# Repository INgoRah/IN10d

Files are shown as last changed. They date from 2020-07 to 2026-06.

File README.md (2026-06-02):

Arduino 1-Wire Homeautomation Base

# Changes
[x] timer based control (different switch table?). Use CLI sw t <bus> <adr> <latch> <bus> <adr> <pio>.
    Default 30 secs at the moment
[x] Host IF for switch table
[x] Host IF for control
[x] Host GPIO signal verified
[x] Switch with same dst does not clear timer if running.
[x] Log latch and switch

# Documentation

## Build
Create a post_extra_script.py to copy over to PI:
Import("env", "projenv")
env.AddPostAction(
    "$BUILD_DIR/${PROGNAME}.elf",
    env.VerboseAction(" ".join([
        "scp ",
        "$BUILD_DIR/${PROGNAME}.hex", "<user>@<ip>:<path>/${PROGNAME}.hex"
    ]), "Copying $BUILD_DIR/${PROGNAME}.hex")
)

Build using PlatformIO: %USERPROFILE%\.platformio\penv\Scripts\platformio.exe run --environment nanoatmega328-deploy

Debugging with "simulation" target

## Features Details

### Alarm handling

Each custom DS2408 generates an alarm signal of > 800 us on the OneWire line. No
other master supports detection of it. But this is a feature of the iButton.
Therefore I need a master to at least monitor the line and signal it to an
other master. The Arduino turned out to be fast and stable to handle basic
light switches in reasonable time compared to a Linux host (threads, updates,
script latency and overhead). So the Arduino controls the light switches.

### Address format and limitations

The adress scheme is aligned with the slave implementation to save space in
the Arduino Nano and speed up the lookup. Only bus and address needs to be known
(and detected in the alarm search).
The latch in the lookup table is only the latch number, no bitmap. Means pressing two
switches at the same time is ignored (first latch taken).

Slaves are based on the OneWireSlave Attiny code uses a format like this:
29 | id | bus | ~id | ~bus | 66 | 77 | CRC
with id: 0 .. F
PIO0/1 are output (usually, but can be configured)
Latch2..7 are input (usually)
A special destination type for other devices (like DS2413) is reserved.
The custom DS2408 implementation also serves a alarm signal of 900 us like
the iButtons do. This avoids frequent polling (would need to be around 200 ms)

### Switching examples ###

A button is pressed. The slave generates an alarm signal on the bus and the Arduino
detects the long signal (> 800 us). It starts polling using the alarm condition
for the (or all) slaves in alarm condition. Reads out the registers and
starts a lookup in the timer table and switch table for commands.

### Measures to overcome limitations

Still the lookup table could be too large and this needs to be mitigated.
- fixed or stable switches in program space: easy to access via different table
  or use custom bootloader for flash storing option
- lookup in EEPROM: cache EEPROM or create new look up table (bus|adr = 4 x 31 lines returns dst by latch index),  max 1 KB

## CLI examples

## I2C format
C3 - channel select like in DS2482
F0 - reset
69 - mode selection: [2] [4]
5A - search first device, wait for search cycle for reading, returns 0 if nothing found or | id | adr [8]
5B - search next device, returns 0 if nothing found or | id | adr [8]
01 - read one event from fifo, status: busy,ok,no_data
02 - add switch entry:  type, bus, adr1, latch, press [0..2], da.bus,da.adr,da.pio
03 - write PIO: type, bus, adr1, pio and release lock, check for an event acknowledging the change
E2 - lock i2c bus and get status, if no events in the queue the lock is released again
78 - Handle ack: pass the sequence number to be acked, this releases the lock

status: alarm bus 3 | alarm bus 2 | alarm bus 1 | alarm bus0
bus select
read out alarm : adr | latch
read out status : write adr | read PIO

### Host Communication

On GPIO low, read status register
Set read pointer:
    Write 0xE1 0xE1
Read one byte (status)
If event data (0x40)
    write 0x1
    status changes to BUSY, wait for OK or NO_DATA
    on ok send read data request
    write 0x96
    read data (on event 9 bytes): type, bus, adr, latch, press, 16 bit data, seq, 0xaa
    seq: 1..0x7f
    read status again and repeat if needed

### Handling events Implementation details:
- check alarm status which resets the gpio, ALARM_STATUS_REGISTER
   iic.i2cWriteSync(iicAdr, 2, Buffer.from([0xE1, 0xA8]));
- read one byte and check for 0x40 otherwise cancel
- request event data, selects status register
  The controller copies the data over from the fifo
  Send CMD_EVT_DATA (= 0x1)
    iic.i2cWriteSync(iicAdr, 1, Buffer.from([0x1]));
    release the bus iic.closeSync();
- read status in a loop till 0
    0 = ok, data is prepared
    1 = busy/waiting to read data
    0x80 no data: return
- select data register, status is READY = 0x4
    iic.i2cWriteSync(iicAdr, 1, Buffer.from([0x96]));
    delay...?
    iic.i2cReadSync(iicAdr, 9, rbuf);
    rbuf[7] contains the sequence number
- send ack
    This will clear the fifo entry and increases the sequence number.
    This also may release the I2C host bus
    iic.i2cWriteSync(iicAdr, 2, Buffer.from([0x78, rbuf[7]]));

### sending commands details
    set read ptr to DS2482_STATUS_REGISTER
    iic.i2cWriteSync(iicAdr, 2, Buffer.from([0xE1, 0xE1]));
    delay(1);
    // wait for ready
    do {
        iic.i2cReadSync(iicAdr, 1, rbuf);
        delay(1);
    } while (rbuf[0] != 0);

    iic.i2cWriteSync(iicAdr, 5, Buffer.from([0x3, bus, id, pio, <level>]));

## Switch configuration

sw : dumps the table
sw r : reads the table from eeprom again
sw s : saves the table into eeprom
sw c : clears the table
sw d <bus> <adr> <latch>: deletes a switch
sw s <bus> <adr> <latch> <dst bus> <dst adr> <dst pio> [type]
	add a switch
sw t <timer type> <bus> <adr> <latch> <dst bus> <dst adr> <dst pio> [type]
	Add a timed switch
    Timed table	timer type: 1 = 20 sec, 2: 30 sec, 3: 1 min, 4: 2 min, 5: 5 mins ...
    Timer on darkness: offset 10
	Timer on darkness with soft off per time if supported (dimmable), time 5 secs: offset 20

    latch 10 .. 17: long press
    latch 0 .. 7: normal press
    latch 20 .. 27: pressing

## EEPROM config space

3 6 0 1 0 0 3 0 80 1D 9 2
            vers=3 tbl@8 len=3
	                timed  @15 timed vers=2 len=0 / Max 40
			       16bit @ 17 vers=0 len=0 / Max 0

start:
pin 0 2 0 20 1 240
pin 2 7 0 60 1 250
pin 0 4 5 40 2 90
stop
pin 0 2 0 eb 0 0
pin 0 2 0 ee 0 0
on
pin 0 2 0 DD 0 254
pin 2 7 0 DD 0 254
off
pin 0 2 0 EB 0 0
pin 2 7 0 EB 0 0

brightness
pin 2 7 0 e3 250 0
pin 0 2 0 e3 250 250

threshold
pin 2 7 0 e5 236 0
pin 0 2 0 e5 228 0

cfg 7 w ff ff ff ff 20 ff ff ff ff ff ff 23 02 00 00 ff ff ff ff FC
             DD
          E4 20 0 A 6 4
cfg 7 w 1 e4 28 0 0 3 3 0 21 0 0 0 0 0 0
= level = 200
= time = 2 min
cfg 2 w 1 C0 30 0 A 3 3 0 21 0 0 0 0 0 0

        R |R |R |SW 1  2  3  4  5  6  7 |CFG 1 2  3  4  5  6  7 |FEA|OFF|MAJ|MIN|TYP
cfg 2 w F8 FF FF FF FF FF FF FF 20 FF FF 23 21 21 21 21 02 10 10
        T|TH|DD|DU|DF|T1|T2|SW 1  2  3  4  5  6  7
cfg 2 w 1 C0 20 00 0A 03 01 ff ff ff FF FF 21 FF FF FF FF FF FF
cfg 2 w 1
cfg 2

cfg 7 w 1
        T|TH|DD|DU|DF|T1|T2|SW 1  2  3  4  5  6  7
cfg 7 w 1 40 10 00 0A 01 01 FF 21 FF FF FF FF FF FF FF FF FF FF FF FF
p 2 7 0 30

cfg 7 w ff ff ff ff 20 ff ff ff ff ff ff 23 02 21 02 ff ff ff ff FC
cfg 1 w ff ff ff ff ff ff ff ff ff ff ff 02 02 02 02 ff ff ff ff FC

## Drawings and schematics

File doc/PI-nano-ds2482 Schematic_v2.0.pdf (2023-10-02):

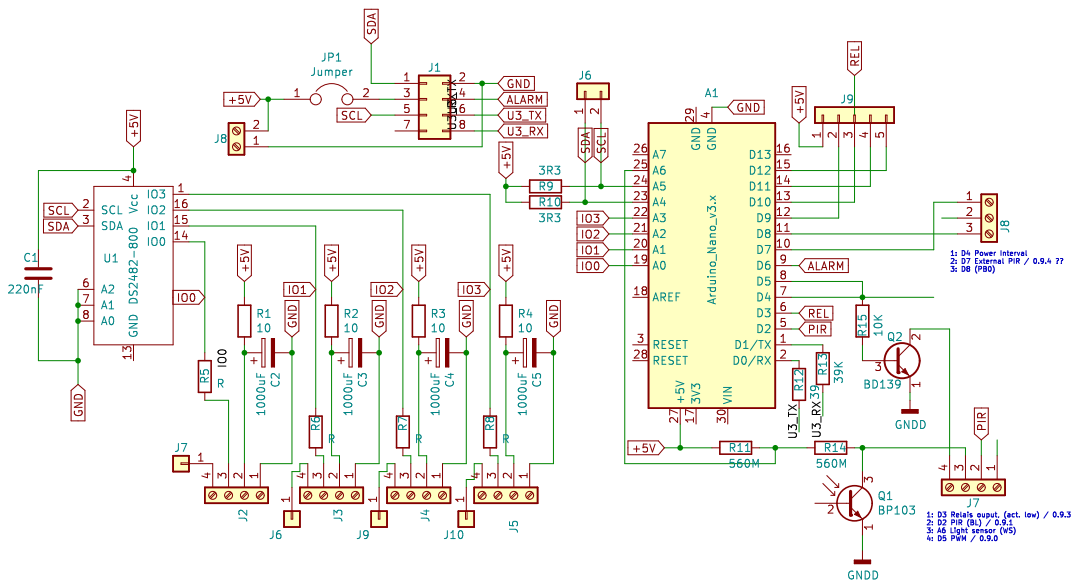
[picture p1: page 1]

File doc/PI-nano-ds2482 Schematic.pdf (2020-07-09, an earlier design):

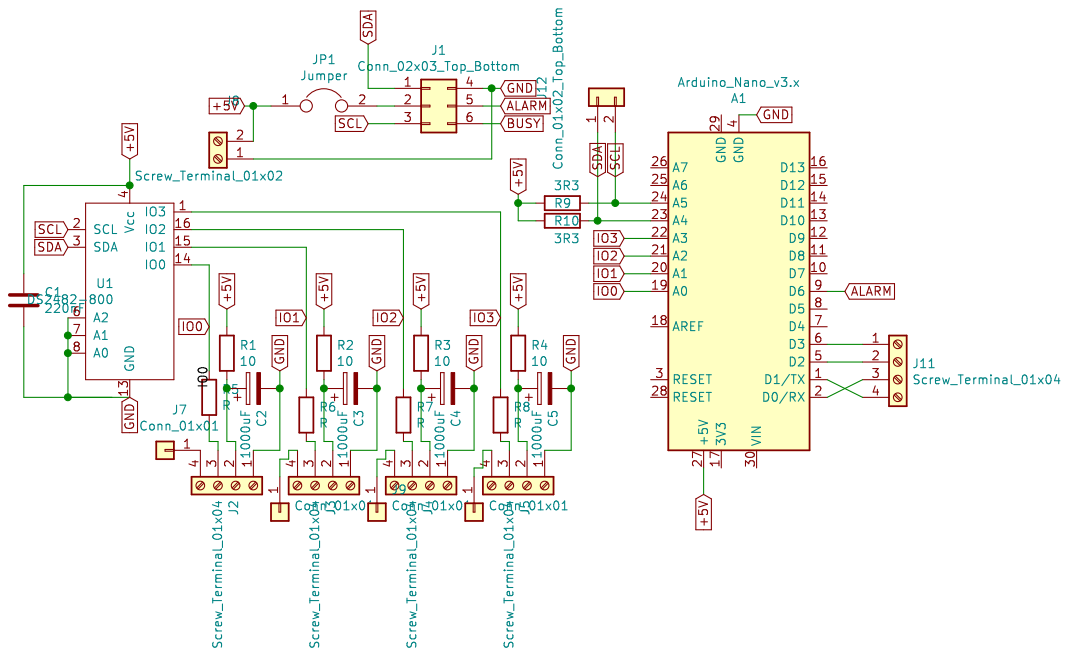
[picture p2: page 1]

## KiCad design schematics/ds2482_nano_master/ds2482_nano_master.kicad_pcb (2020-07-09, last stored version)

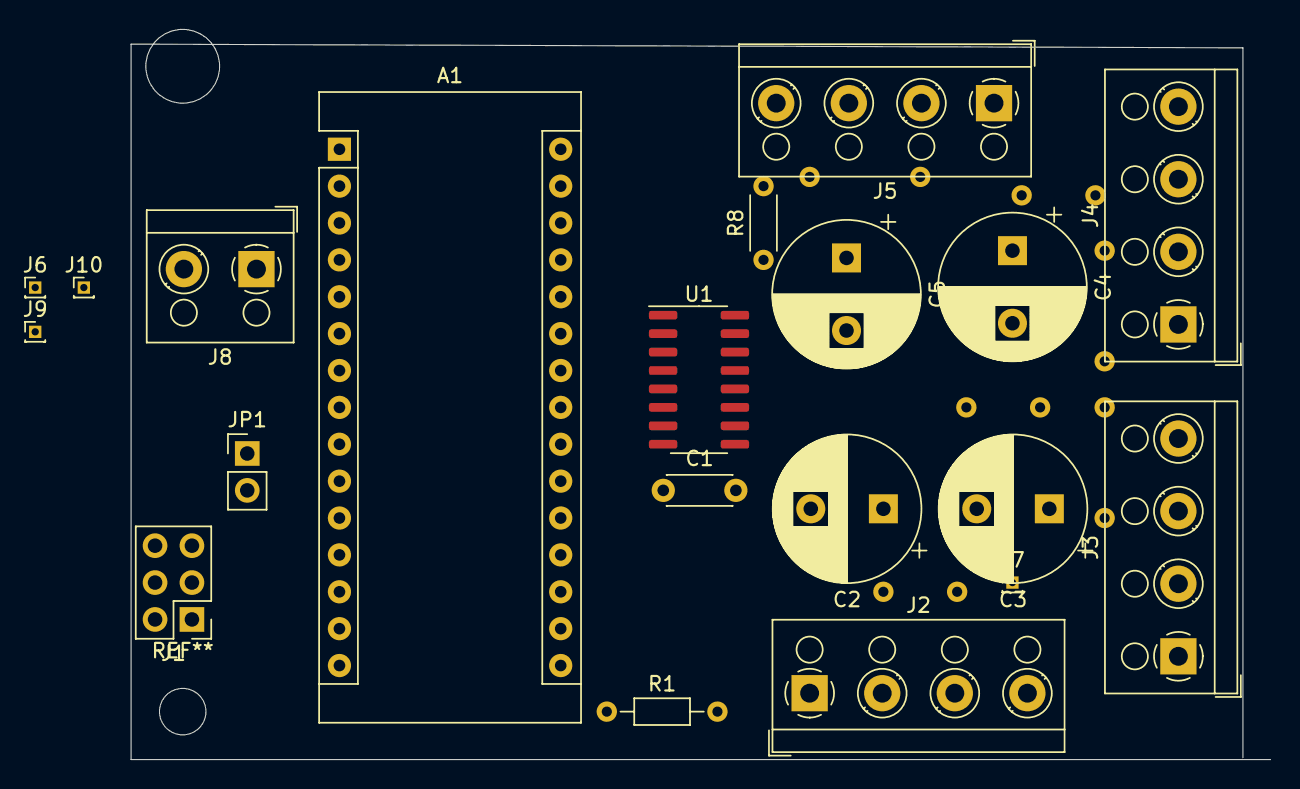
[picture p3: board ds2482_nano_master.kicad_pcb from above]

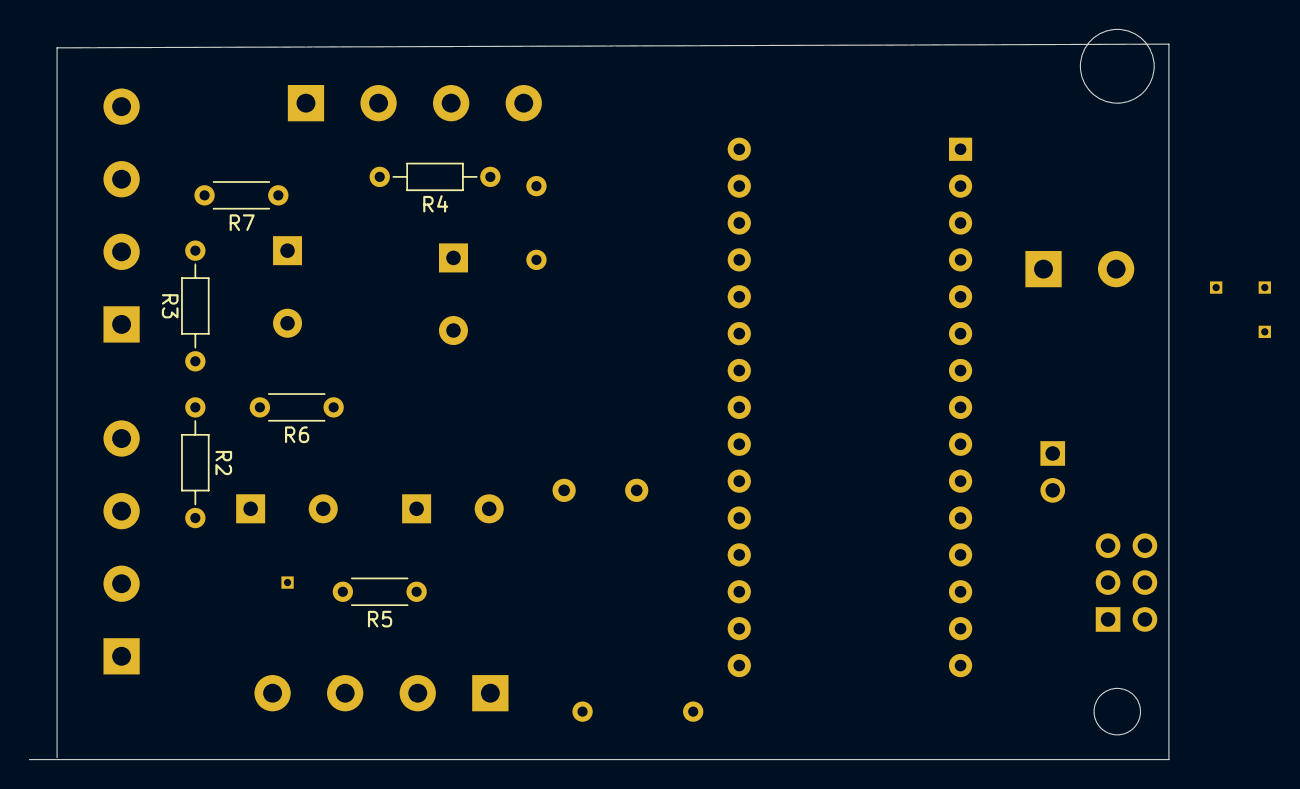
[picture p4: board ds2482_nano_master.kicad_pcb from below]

Board: 2 copper layers, 78.5 x 50.3 mm, 26 parts (6 on the bottom side), 22 nets, no tracks yet.

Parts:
A1: Arduino_Nano_v3.x; Arduino_Nano
C1: 220nF; C_Disc_D4.3mm_W1.9mm_P5.00mm
C2, C3, C4, C5: 1000uF; CP_Radial_D10.0mm_P5.00mm
J1: Conn_02x03_Top_Bottom; PinHeader_2x03_P2.54mm_Vertical
J2, J3, J4, J5: Screw_Terminal_01x04; TerminalBlock_RND_205-00003_1x04_P5.00mm_Horizontal
J6, J7, J9, J10: Conn_01x01; PinHeader_1x01_P1.00mm_Vertical
J8: Screw_Terminal_01x02; TerminalBlock_RND_205-00001_1x02_P5.00mm_Horizontal
JP1: Jumper; PinHeader_1x02_P2.54mm_Vertical
R1, R2, R3, R4: 10; R_Axial_DIN0204_L3.6mm_D1.6mm_P7.62mm_Horizontal
R5, R6, R7, R8: R; R_Axial_DIN0204_L3.6mm_D1.6mm_P5.08mm_Horizontal
U1: DS2482-800; SOIC-16_3.9x9.9mm_P1.27mm

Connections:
+5V: A1.27, C1.1, J8.2, R1.1, R2.1, R3.1, R4.1, U1.4
ALARM: A1.9, J1.5
GND: A1.4, C1.2, C2.2, C3.2, C4.2, C5.2, J1.4, J2.1, J3.1, J4.1, J5.1, J8.1, U1.6, U1.7, U1.8, U1.13
IO0: A1.19, R5.1, U1.14
IO1: A1.20, R6.1, U1.15
IO2: A1.21, R7.1, U1.16
IO3: A1.22, R8.1, U1.1
unnamed: C2.1, J2.2, R1.2
unnamed: C3.1, J3.2, R2.2
unnamed: C4.1, J4.2, R3.2
unnamed: C5.1, J5.2, R4.2
unnamed: J1.2, JP1.2
unnamed: J2.3, R5.2
unnamed: J2.4, J7.1
unnamed: J3.3, R6.2
unnamed: J3.4, J6.1
unnamed: J4.3, R7.2
unnamed: J4.4, J9.1
unnamed: J5.3, R8.2
unnamed: J5.4, J10.1
SCL: A1.24, J1.3, U1.2
SDA: A1.23, J1.1, U1.3

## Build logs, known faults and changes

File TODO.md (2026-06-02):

# Bugs
Pressing a button to permanently switch on light is not working setting level = 100 turns light off

# Improvements

[ ] Separate latch (input) and switch (output) to send two message in case
of auto, switch table or host controlled switch  
[ ] (ongoing) Timer based on light with configurable threshold
    - update brightness on change to slaves 2.7 and 0.2
[ ] Custom timer time per switch  
[ ] (ongoing) Host IF for status read  
[ ] Light independed timed switch. Currently timed switches only if dark  
[ ] Support 16 bit destination address for all PIOs
[ ] Support timed switch from host
[ ] Timed switches retrigger/switch. Now every latch retriggers timer, but it could
    instead switch off again. This needs to be configurable per switch
[ ] Slave based timer time configurable (needs change in owslave)

# PICO Support

## Adaptations

- OneWire Montor (Pull-Up)
- Ports (Analog, digital, PWM)
- IO changes

## Features

### MQTT Receiver (Port switcher)

### MQTT Sender (Temperature, status)

### Change switch table data struct

- address up to 8 PIOs (3 bits)
- optional address up to 8 busses (3 bits)

### Support non custom Addresses

- DS1820 based sensors (requires polling)
- full 1-wire address (except CRC)

# Switch Table
= Switches =
1.11.5 -> 2.3.0 (2D42 | 86)
2.3.4 -> 1.B.1 (D04 | 57)
1.1.7 -> 1.C.1 (5C2 | 59)
2.1.6 -> 2.3.0 (584 | 86)
2.2.3 -> 2.3.0 (8C4 | 86)
1.11.7 -> 1.1.1 (2DC2 | 43)
1.11.27 -> 1.5.0 (2DE2 | 4A)
1.11.25 -> 1.5.1 (2D62 | 4B)
0.6.7 -> 0.5.0 (19C0 | A)
0.6.4 -> 0.8.0 (1900 | 10)
0.5.5 -> 0.8.0 (1540 | 10)
0.5.7 -> 0.6.0 (15C0 | C)
0.5.3 -> 0.1.0 (14C0 | 2)
1.12.7 -> 1.5.1 (31C2 | 4B)
1.12.5 -> 1.1.1 (3142 | 43)
1.12.15 -> 2.7.0 (33C2 | 8E)
1.12.25 -> 0.9.0 (3162 | 12)
1.12.26 -> 2.7.0 (31A2 | 8E)
1.1.6 -> 1.C.1 (582 | 59)
1.7.2 -> 0.9.0 (1C82 | 12)
0.8.5 -> 0.6.0 (2140 | C)
0.8.7 -> 0.8.0 (21C0 | 10)
1.4.6 -> 1.1.1 (1182 | 43)
1.4.4 -> 1.C.1 (1102 | 59)
1.7.6 -> 1.5.0 (1D82 | 4A)
1.7.4 -> 1.5.1 (1D02 | 4B)
1.1.18 -> 1.1.0 (612 | 42)
1.7.2 -> 2.7.0 (1C82 | 8E)
1.1.16 -> 1.5.1 (592 | 4B)
0.6.5 -> 0.1.0 (1940 | 2)
2.2.23 -> 2.7.0 (8E4 | 8E)
1.7.5 -> 1.1.1 (1D42 | 43)
1.4.14 -> 1.5.1 (1112 | 4B)
1.12.8 -> 1.B.1 (3202 | 57)
1.12.17 -> 1.5.0 (31D2 | 4A)
1.7.3 -> 1.B.1 (1CC2 | 57)
1.7.7 -> 0.1.0 (1DC2 | 2)
1.4.16 -> 1.3.0 (1192 | 46)
Size=114/540
= Timed =
Type 21 0.9.1 -> 0.9.0
Type 21 2.7.2 -> 2.7.0
Type 22 1.11.23 -> 0.9.1
Size=9/40

  0: 2 FF 72 0 42 2D 86 4 D 57 C2 5 59 84 5 86 
 16: C4 8 86 C2 2D 43 E2 2D 4A 62 2D 4B C0 19 A 0 
 32: 19 10 40 15 10 C0 15 C C0 14 2 C2 31 4B 42 31 
 48: C2 33 8E 62 31 12 A2 31 8E 82 5 59 82 1C 12 
 64: 21 C C0 21 10 82 11 43 2 11 59 82 1D 4A 2 
 80: 4B 12 6 42 82 1C 8E 92 5 4B 40 19 2 E4 8 
 96: 42 1D 43 12 11 4B 2 32 57 D2 31 4A C2 1C 57 
112: 1D 2 92 11 46 2 15 8 0 15 40 24 12 15 84 
128: 1C 8E 24 12 15 84 1C 8E 8 D2 2C C2
142:

  0: 3 6 E 2 1 FF 72 0 42 2D 86 4 D 57 C2 5 
 16: 59 84 5 86 C4 8 86 C2 2D 43 E2 2D 4A 62 2D 4B 
C0 19 A 0 19 10 40 15 10 C0 15 C C0 14 2 C2 
31 4B 42 31 43 C2 33 8E 62 31 12 A2 31 8E 82 5 
59 82 1C 12 40 21 C C0 21 10 82 11 43 2 11 59 
82 1D 4A 2 1D 4B 12 6 42 82 1C 8E 92 5 4B 40 
19 2 E4 8 8E 42 1D 43 12 11 4B 2 32 57 D2 31 
4A C2 1C 57 C2 1D 2 92 11 46 2 40 8 0 15 40 
24 12 15 84 1C 8E 1 8E 3 0 15 40

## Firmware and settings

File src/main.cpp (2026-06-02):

/* LICENSE
 *
 */
/*
 * Includes
 */
#include <avr/sleep.h>
#include <avr/pgmspace.h>
#include <avr/wdt.h>

#include "main.h"

#define wdr wdt_reset

/*
 * Library classs includes
 */
#include <Wire.h>
#include <OneWireBase.h>
#include <DS2482.h>
#include "WireWatchdog.h"
#include "TwiHost.h"
#ifdef CLI_SUPPORT
#include "CmdCli.h"
#endif
#include "OwDevices.h"
#include "SwitchHandler.h"

/*
Used pins
(D0 .. D7 = PD0 .. PD7,
 D8 .. D13 = PB0 .. PB5,
 A0 .. A5 = PC0 .. PC5):
D2 - Internal PIR, maps to 0.9.1
D3 -
D4 - Misc Alarm PIN, maps to 0.9.2
D5 - PWM output (dimed LED) via open coollector transistor, maps to 0.9.0
D6 - used for alarm signal to host (class TwiHost)
D7 - Power Interval
D8 (PB0) - External PIR, maps to 0.9.4
D9 -
D10 - Relais ouput, negative polarity - active switching GND, maps to 0.9.3
D11 -
D12 -
D13 - built in LED
A0..A4 - 1-wire monitor
A6 (ADC6) - Light sensor (analog)
*/
/*
Virtual adress mapping
0.9.0 - output PWM on D5
0.9.1 - output D9
0.9.2 - input Misc Alarm PIN / D12
0.9.3 - output D10
0.9.4 - D11
0.9.5 - ignored
0.9.7 - ignored
x - input D3
*/

/*
 * Local constants
 */
#define LED_ON() digitalWrite(13, 1); \
					ledOn = 1;
#define LED_OFF() digitalWrite(13, 0); \
					ledOn = 0;
#define HOST_SLAVE_ADR 0x2f
#define ALARM_SRCH_RETRY 15

byte debug;
byte pins;

/*
 * Objects
 */
TwiHost host;
DS2482 ds1(0);
OwDevices ow;
SwitchHandler swHdl (&ow);
OneWireBase *ds = &ds1;

uint8_t sec;
uint8_t min;
uint8_t hour;
uint8_t light;
byte light_sensor = 1;
uint16_t pow_imp;

#if !defined(AVRSIM)

WireWatchdog wdt0(A0);
WireWatchdog wdt1(A1);
WireWatchdog wdt2(A2);
WireWatchdog wdt3(A3);
#if MAX_BUS > 3
WireWatchdog* wdt[MAX_BUS] = { &wdt0, &wdt1, &wdt2, &wdt3 };
#else
WireWatchdog* wdt[MAX_BUS] = { &wdt0, &wdt1, &wdt2 };
#endif

#ifdef CLI_SUPPORT
CmdCli cli;
#endif
/*
 * Local variables
 */
byte alarmSignal, pinSignal, ledOn = 0;
#ifdef EXT_DEBUG
byte wdFired;
#endif
#if 0
unsigned long wdTime = 0;
#endif
static unsigned long alarmPolling = 0;
uint8_t *hostBuf = NULL;

/*
* Function declarations
*/
#ifdef EXT_DEBUG
static void ledBlink();
unsigned long ledOnTime = 0;
#endif
static void check_light(byte mode);
void light_loop();
void pin_loop();
void alarm_loop();

/*
* Function definitions
*/
void setup() {
	int i;
	/* the watchdog timer remains active even after a system reset (except a
	 * power-on condition), using the fastest prescaler value.
	 * It is therefore required to turn off the watchdog early
	 * during program startup */
	MCUSR = 0;
	wdt_disable();
	Serial.begin(115200);

	debug = 3;
	pins = 0xff;
	Serial.print(F("IN10D "));
	Serial.println(F(VERS_TAG));
	//digitalWrite(3, 1);
	//pinMode(3, OUTPUT);
	delay (10);
	// host.onCommand(hostCommand);
	host.begin (HOST_SLAVE_ADR);
#ifdef EXT_DEBUG
	wdFired = 0;
#endif
	ow.begin(ds);
	// reads also mode and debug
	swHdl.begin(ds);
	if (pins & 0x1)
		pinMode(4, INPUT_PULLUP);
	if (pins & 0x2)
		pinMode(3, INPUT);
	byte mask = 0x10;
	for (i = 9; i < 13; i++) {
		if (pins & mask) {
			digitalWrite(i, HIGH);
			pinMode(i, OUTPUT);
		}
		mask = mask << 1;
	}
	/* enable interupts on PB0 (= D8), Power impulse */
	PCMSK0 |= (_BV(PCINT0));
	/* enable interrupts for the 1-wire monitor */
	PCMSK1 |= (_BV(PCINT8) | _BV(PCINT9) | _BV(PCINT10) | _BV(PCINT11));
	if (pins != 0) {
		/* enable interupts on PD2, PD3, PD7 (4, 7) (= D2, D3, D4, D7) */
		PCMSK2 |= (_BV(PCINT18) | _BV(PCINT19) | _BV(PCINT23) /*| _BV(PCINT20) */);
	}
	PCIFR = _BV(PCIF0) | _BV(PCIF1) | _BV(PCIF2); // clear any outstanding interrupt
	PCICR = _BV(PCIE0) | _BV(PCIE1) | _BV(PCIE2); // enable interrupt for the group
	delay (50);
#if 0
	wdTime = millis();
#endif
	dumpCfg();
#ifdef CLI_SUPPORT
	cli.begin(&ow);
#endif
	wdt_enable(WDTO_4S);
	WDTCSR |= _BV(WDIE);

	// todo: update cache
	ow.cacheInit();
	swHdl.initialStates();
	// poll as soon as possible
	alarmPolling = 0;
	host.addEvent (SYS_START, 0, 9, 0);
	check_light(0);
	wdt_reset();
	delay(200);
	check_light(0xff);
}

#if 0
ISR(WDT_vect, ISR_NAKED)
{
	uint8_t *upStack;
	uint16_t uAddress = 0;

	// Setup a pointer to the program counter. It goes in a register so we
	// don't mess up the stack.
	upStack = (uint8_t*)SP;
	// The stack pointer on the AVR micro points to the next available location
	// so we want to go back one location to get the first byte of the address
	// pushed onto the stack when the interrupt was triggered. There will be
	// PROGRAM_COUNTER_SIZE bytes there.
	++upStack;
	memcpy(&uAddress, upStack, 2);
	Serial.print("SP=0x");
	Serial.println(2 * uAddress, HEX);

	Serial.print("SP-1=0x");
	--upStack;
	memcpy(&uAddress, upStack, 2);
	Serial.println(2 * uAddress, HEX);

	Serial.print("SP-2=0x");
	--upStack;
	memcpy(&uAddress, upStack, 2);
	Serial.println(2 * uAddress, HEX);

	Serial.flush();
	wdt_enable(WDTO_120MS);
	while (true)
		;
}
#endif

/* interupt on PORTB:
 PB0 (= D8) unused  */
ISR (PCINT0_vect)
{
	uint8_t pinb;

	pinb = PINB;
	if ((pinb & _BV(PB0)) == 0)
		pinSignal |= 0x10;
}

/* interrupt handling for change on 1-wire */
ISR (PCINT1_vect) // handle pin change interrupt for A0 to A4 here
{
	uint8_t i;

	for (i = 0; i < MAX_BUS; i++) {
		if (wdt[i]->alarmCheck()) {
			alarmSignal++;
#ifdef EXT_DEBUG
			ledOnTime = millis();
			LED_ON();
#endif
		}
	}
	/* */
#if 0
	wdTime = millis();
#endif
}

/* Connector on D2 (PD2 / PIR internal)
   D7 (PD7 / PIR external)
   custom wire D4 (PD4 / external Alarm) */
ISR (PCINT2_vect) // handle pin change interrupt for A0 to A4 here
{
	static uint8_t pind_old = 0;
	uint8_t pind;

	/* just check for changes */
	pind = PIND;
	/* check for change to high */
	if ((pind & _BV(PD2)) && (pind_old & _BV(PD2)) == 0)
		pinSignal |= 0x1;
	/* report on change to low level */
	if (((pind & _BV(PD4)) == 0) && (pind_old & _BV(PD4)))
		pinSignal |= 0x2;
	/* Power Interval (500/1 KWh = 2 Wh) */
	if (((pind & _BV(PD7)) == 0) && (pind_old & _BV(PD7)))
		pinSignal |= 0x8;

	if ((pind & _BV(PD3)) && (pind_old & _BV(PD3)) == 0)
		pinSignal |= 0x4;

	pind_old = pind;
}

#ifdef EXT_DEBUG
static void ledBlink()
{
	if (millis() - ledOnTime > 300) {
		if (ledOn) {
			ledOnTime = millis();
			LED_OFF();
		}
		else if (wdFired) {
			LED_ON();
			ledOnTime = millis();
		}
	}
}
#endif

void dumpCfg()
{
	Serial.print(F(" mode="));
	Serial.print(swHdl.mode);
	Serial.print(F(" debug="));
	Serial.print(debug);
	Serial.print(F(" light thr ="));
	Serial.print(swHdl.light_thr);
	Serial.print(F(" light sensor="));
	Serial.print(light_sensor);
	Serial.print(F(" pins="));
	Serial.print(pins, HEX);
	Serial.print(F(" light="));
	Serial.print(light);
}

static void check_light(byte mode)
{
	uint16_t t;
	uint8_t adr[8];

#ifdef INTERN_PIOS
	if (light_sensor) {
		ADCSRA = (1<<ADPS2) | (1<<ADPS1) | (1<<ADEN);
		_delay_us (150);
		t = analogRead(A6);
		ADCSRA = 0;
		// filter out minor change
	} else
#endif /* INTERN_PIOS */
	adr[0] = 0x20;
	ow.adrGen(0, adr, 2);
	t = ow.adcRead(0, adr, 1, mode);
	if (mode == 0)
		// just start conversion
		return;

	// filter out minor change
	t = (t >> 2) & 0xFC;
	// average the last 4 measurements
	t = (3 * light + t) / 4;
	if (light != t || mode == 0xff) {
		light = t;
		// inform 2.7
		adr[0] = 0x29;
		ow.adrGen(2, adr, 7);
		if (debug > 3) {
			Serial.print(F(" update light="));
			Serial.println(light);
		}
		ow.ds2408xPinSet(2, adr, 0, 0, 0xE3, light);
		// force polling (if watchdog happend)
		alarmPolling = 0;
		host.addEvent (TYPE_BRIGHTNESS, 0, 9, light);
	}
}

void light_loop()
{
	static unsigned long sec_time = 0;
	static uint8_t mode = 0;

	if ((millis() - sec_time) < 1000)
		return;
	sec_time = millis();
	if (mode == 1 && sec == 2) {
		/* next second read out conversion results */
		check_light(1);
		mode = 0;
	}
	if (sec++ == 60) {
		sec = 0;
		if (min++ == 60) {
			min = 0;
			if (hour++ == 24)
				hour = 0;
		}
		// check brightness every 10 mins
		if ((min % 5) == 0 && mode == 0) {
			check_light(0);
			mode = 1;
		}
	}
}

void pin_loop()
{
	if (pinSignal == 0)
		return;
#ifdef DEBUG
	if (debug > 4) {
		Serial.print(F("PIN Signal: "));
		Serial.println(pinSignal);
	}
#endif

#ifdef INTERN_PIOS
	// interrupt to host
	if (pinSignal & 0x1 && pins & 0x1)
		swHdl.switchHandle(0, 0, 1);
	if (pinSignal & 0x2 && pins & 0x2)
		swHdl.switchHandle(0, 0, 0x2);
	if (pinSignal & 0x4 && pins & 0x4)
		swHdl.switchHandle(0, 0, 0x4);
#endif /* INTERN_PIOS */
	if (pinSignal & 0x8 && pins & 0x8) {
		pow_imp++;
		host.addEvent (POWER_IMP, 0, 9, pow_imp);
	}
	pinSignal = 0;
}

void alarm_loop()
{
	if (!alarmSignal)
		return;
	alarmPolling = millis();
	/* the alarmhandler will set the alarm signal to the host
		after the event data is prepared. Otherwise a host could
		disturb our switching process */
	if (swHdl.mode & MODE_ALRAM_HANDLING) {
		byte retry;
		for (byte i = 0; i < MAX_BUS; i++) {
			if (wdt[i]->alarm) {
				wdr();
				retry = ALARM_SRCH_RETRY - 1;
				while (!swHdl.alarmHandler(i)) {
					if (--retry == 0)
						break;
					delay (ALARM_SRCH_RETRY - retry);
					wdr();
				}
				if (retry > 0) {
					wdt[i]->alarm = false;
				} else {
					if (ds->last_err) {
						// lets retry next loop
#ifdef DEBUG
						log_time();
						Serial.print(i);
						Serial.print(F(": alarm retry exceeded "));
						Serial.println(ds->last_err);
						/* TODO This seem to cause watchdog timeouts on the slaves!
						because a reset might not be followed by further actions */
#endif
						wdr();
						return;
					}
					wdt[i]->alarm = false;
				}
			}
		}
	} else {
		uint8_t ch = 0;
		for (byte i = 0; i < MAX_BUS; i++) {
			if (wdt[i]->alarm) {
				if (i != 0) {
					// if there are more than 1 busses signaling alarm
					// report it as 0xf to the host
					ch = 0xF;
				} else {
					ch = i;
				}
			}
		}
		host.setAlarm(ch);
	}
	alarmSignal--;
}

void loop()
{
	host.loop();
#ifdef EXT_DEBUG
	if (ledOnTime != 0 && !alarmSignal) {
		ledBlink();
	}
#endif
	if ((swHdl.mode & MODE_HOST) == 0) {
		/* if there is any host data transfer, avoid conflicts on the I2C bus
		* and skip handling - transfer should be finished very quickly
		* within 50 ms
		*/
		if (host_lock && ((millis() - host_lock) < 50)) {
			wdr();
			return;
		}
	}
	pin_loop();
	if (swHdl.mode & MODE_AUTO_SWITCH)
		swHdl.loop();
	alarm_loop();
	if (swHdl.mode & MODE_ALRAM_POLLING) {
		light_loop();
		if (millis() - alarmPolling > 2000) {
			alarmPolling = millis();
			for (byte i = 0; i < MAX_BUS;i++) {
				wdr();
				swHdl.alarmHandler(i);
			}
		}
	}
#if 0
	if (swHdl.mode & MODE_WATCHDOG && (wdFired == 0 && millis() - wdTime > 5000)) {
		wdFired = 1;
		Serial.println(F("Watchdog!"));
		//LED_ON();
		ledOnTime = millis();
	}
#endif
#ifdef CLI_SUPPORT
	cli.loop();
#endif
	wdr();
	 /*else
		sleep_cpu();*/
	sleep_enable();
	// timer fires every micro ... :-( - maybe hold it?
	set_sleep_mode(SLEEP_MODE_IDLE);
	// other sleep modes were not working, not woken up...
	sleep_cpu();
	sleep_disable();
	wdr();
}
#endif /* AVRSIM */

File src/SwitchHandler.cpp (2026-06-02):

#include <main.h>
#include "CmdCli.h"
#include "SwitchHandler.h"
#include "OwDevices.h"
#include <TwiHost.h>

extern TwiHost host;

struct _timer_item {
	/* timestamp of start */
	unsigned long ms;
	/* seconds to switch off */
	uint16_t secs;
	uint8_t base_type;
	uint8_t id;
	/* switch off: */
	union d_adr_8 dst;
}tmr_list[MAX_TIMER];

struct _dim_tbl dim_tbl[MAX_DIMMER];

struct _sw_tbl sw_tbl[MAX_SWITCHES];
struct _sw_tbl16 sw_tbl16[2];

/* need switch off time! */
struct _sw_tim_tbl timed_tbl[MAX_TIMED_SWITCH];

SwitchHandler::SwitchHandler()
{
	memset (dim_tbl, 0, sizeof(dim_tbl));

	for (int i = 0; i < MAX_TIMER; i++) {
		tmr_list[i].secs = 0;
	}
	cur_latch = 0;
	/* default level for PIR detection on */
	dim_on_lvl = 63;
	light_thr = 225;
}

SwitchHandler::SwitchHandler(OwDevices* devs)  : SwitchHandler()
{
	this->_devs = devs;
}

uint8_t SwitchHandler::bitnumber()
{
	int i, res = 1;

	for (i = 0x1; i <= 0x80; i = i << 1) {
		if (cur_latch & i) {
			cur_latch -= i;
			return res;
		}
		res++;
	}
	/* invalid */
	return 0xff;
}

extern byte pins;
void SwitchHandler::initSwTable()
{
	uint16_t len, pos, mylen;
	uint8_t vers;

	vers = eeprom_read_byte((const uint8_t*)0);
	if (vers > 2) {
		//  0      1     2       3          4          5     6  7      8 ...
		// vers | pos | mode | debug | ligthsensor | pins |  len    | tbl ... | ...
		pos = eeprom_read_byte((const uint8_t*)1); // should be 6
		mode = eeprom_read_byte((const uint8_t*)2);
		debug = eeprom_read_byte((const uint8_t*)3);
		light_sensor = eeprom_read_byte((const uint8_t*)4);
		pins = eeprom_read_byte((const uint8_t*)5);
	} else {
		//  0      1     2    3     4 ...
		// vers | res |   len    | tbl ... | ...
		pos = 2;
		mode = MODE_ALRAM_HANDLING | MODE_ALRAM_POLLING | MODE_AUTO_SWITCH;
		debug = 1;
		light_sensor = 1;
		pins = 0xff;
	}
	len = eeprom_read_word((const uint16_t*)pos);
	pos += 2;
	if (len > sizeof(sw_tbl)) {
		//Serial.print(F("table exceed limit to "));
		mylen = sizeof(sw_tbl) - 1;
		Serial.println(mylen);
	} else
		mylen = len;
	if (len != 0xFFFF && vers != 0xff) {
#ifdef DEBUG
		/*Serial.print(F(" vers="));
		Serial.print(vers);*/
		Serial.print(F(" tbl@"));
		Serial.print(pos);
		Serial.print(F(" len="));
		Serial.print(len);
		Serial.print(F(" / Max "));
		Serial.print((uint16_t)sizeof(sw_tbl));

#endif
		eeprom_read_block((void*)sw_tbl, (const void*)pos, mylen);
	}
	/* read next (timer) table*/
	pos += len;
	vers = eeprom_read_byte((const uint8_t*)pos);
	if (pos % 2 != 0) {
		Serial.println(F("unaligned"));
	}
	len = eeprom_read_word((const uint16_t*)(pos + 2));
	if (len > sizeof(timed_tbl)) {
		//Serial.print(F("tim table exceed, limit to "));
		mylen = sizeof(timed_tbl) - 1;
		Serial.println(mylen);
	} else
		mylen = len;
	pos += 4;
	if (len != 0xFFFF && vers != 0xff) {
#ifdef DEBUG
		Serial.print(F(" timed@"));
		Serial.print(pos);
		/*Serial.print(F(" timed vers="));
		Serial.print(vers);*/
		Serial.print(F(" len="));
		Serial.print(len);
		Serial.print(F(" / Max "));
		Serial.print((uint16_t)sizeof(timed_tbl));
#endif
		if (len > sizeof(timed_tbl))
			len = sizeof(timed_tbl);
		eeprom_read_block((void*)timed_tbl, (const void*)pos, mylen);
	}
	vers = eeprom_read_byte((const uint8_t*)0);
	if (vers > 2 && len != 0xffff) {
		pos += len;
		vers = eeprom_read_byte((const uint8_t*)pos);
		pos += 2;
		if (pos % 2 != 0) {
			Serial.println(F("unaligned"));
		}
		len = eeprom_read_word((const uint16_t*)pos);
#ifdef DEBUG
		Serial.print(F(" 16bit@"));
		Serial.print(pos);
		Serial.print(F(" vers="));
		Serial.print(vers);
		Serial.print(F(" len="));
		Serial.print(len);
		Serial.print(F(" / Max 0 "));
#endif
	}
#ifdef DEBUG
	Serial.println();
#endif
}

uint16_t SwitchHandler::getLen(uint8_t max, uint16_t elSize)
{
	uint16_t len = 0, i;
	union d_adr_8 dst;
	union s_adr src;

	for (i = 0; i < max; i++) {
		src.data = sw_tbl[i].src.data;
		dst.data = sw_tbl[i].dst.data;
		if (src.data == 0 ||
			(src.data == 0xffff && dst.data == 0xff))
			continue;
		len += elSize;
	}

	return len;
}

void SwitchHandler::saveSwTable(uint8_t vers_force = 0)
{
	uint16_t pos = 6;
	uint16_t sw_tbl_len = 0;
	uint16_t sw_tim_len = 0;

	sw_tbl_len = getLen(MAX_SWITCHES, sizeof(struct _sw_tbl));
	sw_tim_len = getLen(MAX_TIMED_SWITCH, sizeof(struct _sw_tim_tbl));
	Serial.println();
	// set version
	if (vers_force == 2) {
		// force to vers 2
		eeprom_update_byte((uint8_t*)0, (uint8_t)2);
		eeprom_update_word((uint16_t*)2, sw_tbl_len);
		eeprom_update_block((const void*)sw_tbl, (void*)4, sw_tbl_len);
		//  0      1     2    3     4 ...
		// vers | res |   len    | tbl ... | ...
		pos = 4;
	} else {
		//  0      1     2       3          4          5     6  7      8 ...    8 + len
		// vers | pos | mode | debug | ligthsensor | pins |  len    | tbl ... | timver | timlen | timtbl ...
		eeprom_update_byte((uint8_t*)0, (uint8_t)3);
		eeprom_update_byte((uint8_t*)1, (uint8_t)6);
		//  0      1     2       3          4          5      6
		// vers | pos | mode | debug | ligthsensor | pins |  len    | tbl ... | ...
		eeprom_update_byte((uint8_t*)2, (uint8_t)mode);
		eeprom_update_byte((uint8_t*)3, (uint8_t)debug);
		eeprom_update_byte((uint8_t*)4, (uint8_t)light_sensor);
		eeprom_update_byte((uint8_t*)5, (uint8_t)pins);
		eeprom_update_word((uint16_t*)6, sw_tbl_len);
		//pos += 2;
		pos = 8;
		eeprom_update_block((const void*)sw_tbl, (void*)8, sw_tbl_len);
	}
	/* write next (timer) table */
	pos += sw_tbl_len;
	/* timed table, version 2 ... */
	eeprom_update_byte((uint8_t*)pos, (uint8_t)2);
	pos += 2;
	eeprom_update_word((uint16_t*)pos, sw_tim_len);
	pos += 2;
	eeprom_update_block((const void*)timed_tbl, (void*)pos, sw_tim_len);
	pos += sw_tim_len;
	if (vers_force != 2) {
		/* 16 dst table, version 1 ... */
		eeprom_update_byte((uint8_t*)pos, (uint8_t)1);
		pos += 2;
		eeprom_update_word((uint16_t*)pos, 3);
		pos += 2;
		eeprom_update_block((const void*)timed_tbl, (void*)pos, 3);
	}
#ifdef EXT_DEBUG
	Serial.print(F("EEPROM saved, "));
	Serial.print(pos + sw_tim_len);
	Serial.println(F(" bytes"));
#endif
	/* dim table ... */
}

void SwitchHandler::begin(OneWireBase *ow)
{
	this->ds = ow;
	mode = MODE_ALRAM_HANDLING | MODE_ALRAM_POLLING | MODE_AUTO_SWITCH;

	initSwTable();
	/* Specific devices and our own pin having a dimmer feature */

	/* dimmer 1 / stairs OG */
	dim_tbl[0].dst.da.bus = 2;
	dim_tbl[0].dst.da.adr = 7;
	/* dimmer 2 / stairs UG */
	dim_tbl[1].dst.da.bus = 0;
	dim_tbl[1].dst.da.adr = 2;
	dim_tbl[1].dst.da.pio = 0;
#if 0
	/* dimmer 3 */
	dim_tbl[2].dst.da.bus = 1;
	dim_tbl[2].dst.da.adr = 3;
#endif
}
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

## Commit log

2020-07-03 first switcher version
    [ds2482_nano_master.kicad_pcb, ds2482_nano_master.sch]
2020-07-03 CLI and device handling split
    search via I2C
2020-07-03 Switch matrix drafted
    [devices.xlsx]
2020-07-09 Add Schematic
2020-07-09 Add missing files update readme
    [ds2482_nano_master.kicad_pcb, ds2482_nano_master.sch]
2020-08-30 Split of TWI host and Watchdog
    Channel addressing (WIP)
    Switch table from EEPROM
    Adress scheme change
2020-11-13 temperature experiments
    host update queue
2020-11-23 New dataformat for source switches
2020-12-07 Refactoring and new features
    - timed switches (currently default time 15 secs)
    - long press detection (pressing and press)
    - dimmer (PWM devices)
2020-12-09 Added logging feature
    PIR sensor directly at PD2 / D2
2021-01-19 some clean up
    host interface started to optimize
    switch level handling
2021-04-22 Ongoing switch handling
2021-04-22 Class optimization and host interface improvements
    Fix for missing I2C data: need copy the data in event callback
    unit tests for switch cases
    [CmdCli.cpp, OwDevices.cpp, SwitchHandler.cpp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]
2021-04-22 remove files from repo
    [devices.xlsx]
2021-11-02 Improvements
    - Class optimization
    - Added larger PIO union for more pios in addition
    to the 8 bit destination incl. mapping
    - own pins extended with adr #9:pin (except pin 5 = pio0 for PWM)
    - lots of host interface improvements (WIP)
    - improved unit tests
2021-11-02 Adds Light sensor based switching
2021-11-02 Handle multiple latch bits as on auto switching now
    latch and the output is signaled
2021-11-02 CLI improvements
    use global bus and adr if not specified make shorter inputs possible
    [CmdCli.cpp]
2021-11-02 Soft (for dimmer) off and other timer types/times. Now timers are also supported if not dark
    CLI remembers bus and address for pio and status commands
    Adds a configurable light threshold and a max dimmer on level (possible to limit in the night)
    Other cleanup and optimizations
2021-11-02 Lots of clean up
    dim stage correction for internal PWM
    Add two pins of internal controller for PIR and state
    Soft dim down on switching on (nice demo feature)
    [CmdCli.cpp, OwDevices.cpp, SwitchHandler.cpp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]
2021-12-10 Caching of PIO to speed up switching
    Saves time for reading the PIO via 1-wire
2022-07-19 Power Interval support
2022-07-19 more for power
2022-07-21 I2C timeout handling 1st
2022-07-21 I2C timout 2nd
2022-07-25 Lets include the hash for version prints
2022-12-28 set host alarm by alarmHandler only
    printing optimizations
2022-12-29 Error improvements and ch cache
    [SwitchHandler.cpp, main.cpp]
2022-12-31 Error handling improve (3)
    [main.cpp]
2023-03-25 Logging and error handling improvements Stability and robostness on low level OneWire handling
    [CmdCli.cpp, OwDevices.cpp, SwitchHandler.cpp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]
2023-03-25 SW Host lock cacheInit and initial states (for timer IO) in case of reboot
    [CmdCli.cpp, OwDevices.cpp, SwitchHandler.cpp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]
2023-03-28 Productive compile switch to reduce memory
2023-09-09 Add new pin header for output control
2023-10-02 fixed power pin
2025-11-18 Add simply pio run CI test
    Fix exception in pre_script.py
    Add post script sample
2025-11-18 New pin level and timer set support Draft external ADC (for light) support and auto switch brightness setting
2025-11-18 Add ADC read out from DS2450 chips
    Change intern adr to 0 (and bus stays 0) - no longer used
    Optional compile in intern PIOs
    Disable soft off support
    [CmdCli.cpp, OwDevices.cpp, SwitchHandler.cpp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]
2025-11-18 Init devices version and update selected ones
    debug levels and watchdog
2026-06-02 fix version check and light loop
    [TwiHost.cpp, main.cpp]
